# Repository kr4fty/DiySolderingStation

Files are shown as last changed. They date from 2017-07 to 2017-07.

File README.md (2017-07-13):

# Soldering Station 

Diy Estación de soldado con Atmega328 (Arduino UNO), compatible con HAKKO 936/937/928/926

## Información

Estacion de soldado hecho sobre un Atmega328, utilizando un Lapiz de una estación Hakko.

A diferencia de la estación original, esta alimenta a la Punta/Lapíz con corriente alterna (CA, 24Vac).

ATENCIÓN: Tener en cuenta que este Lapiz utiliza un PTC para el sensado de la temperatura y NO una termocupla.

<p align="center">
  <br><br>
  <b>Lapiz utilizado</b><br>
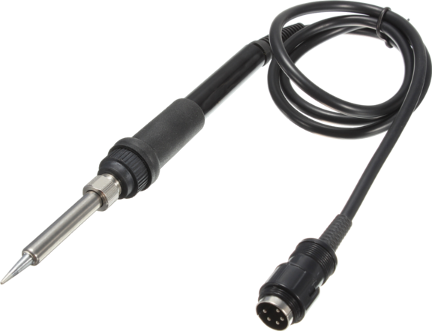
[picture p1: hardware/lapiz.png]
  
  <br>
</p>

## Caracteristicas

  * ESD, Antiestático
  * Tensión: 24 Vac 
  * Rango de temperaturas: 120-480 ºC.
  * Potencia: 50 W

## Partes

  * LCD del tipo I²C: se utilizó un lcd de un Motorola C115 (chipset ST7558)
  * Encoder rotatorio para chasis
  * Punta/lapiz de Estación de soldado, compatible con HAKKO 907 (DIN 5 ESD)
  * Botón para chasis
  * Controlador (incluido en el repositorio)

## Software

Depende de las librerias:
  * [ArduinoPID](https://github.com/br3ttb/Arduino-PID-Library): Librería para el control de la temperatura por medio de un PID
  * [ST7558](https://github.com/kr4fty/ST7558-Motorola-C115-LCD-Library): Driver para manejar el LCD
  * [TimerOne](https://github.com/PaulStoffregen/TimerOne): para el Control de Fase de la tensión de alimentación
  * [EnableInterrupt](https://github.com/GreyGnome/EnableInterrupt): Para habilitar tanto las interrupciones externas como las del tipo Pin-Change
  * [EncoderPCI](https://github.com/kr4fty/EncoderPCI): Se encarga de manejar el Encoder

## Hardware

<p align="center">
  <br><br>
  <b>Circuito eléctrico</b><br>
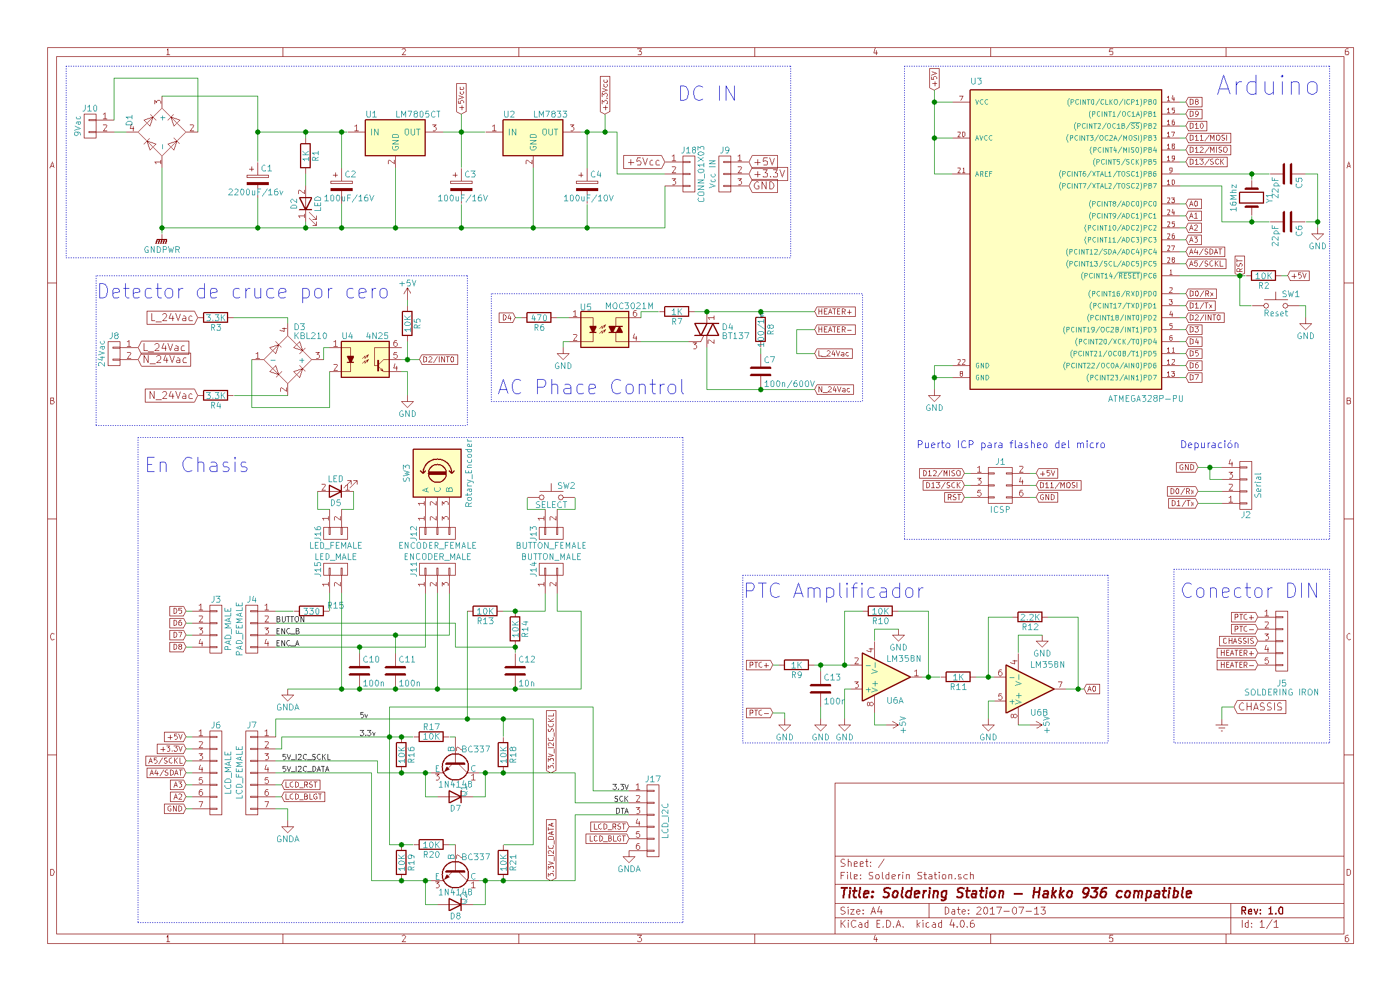
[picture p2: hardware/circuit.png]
  
  <br>
</p>

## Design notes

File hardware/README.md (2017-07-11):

## About

Created with KiCAD 4.0.6

Tapia Favio

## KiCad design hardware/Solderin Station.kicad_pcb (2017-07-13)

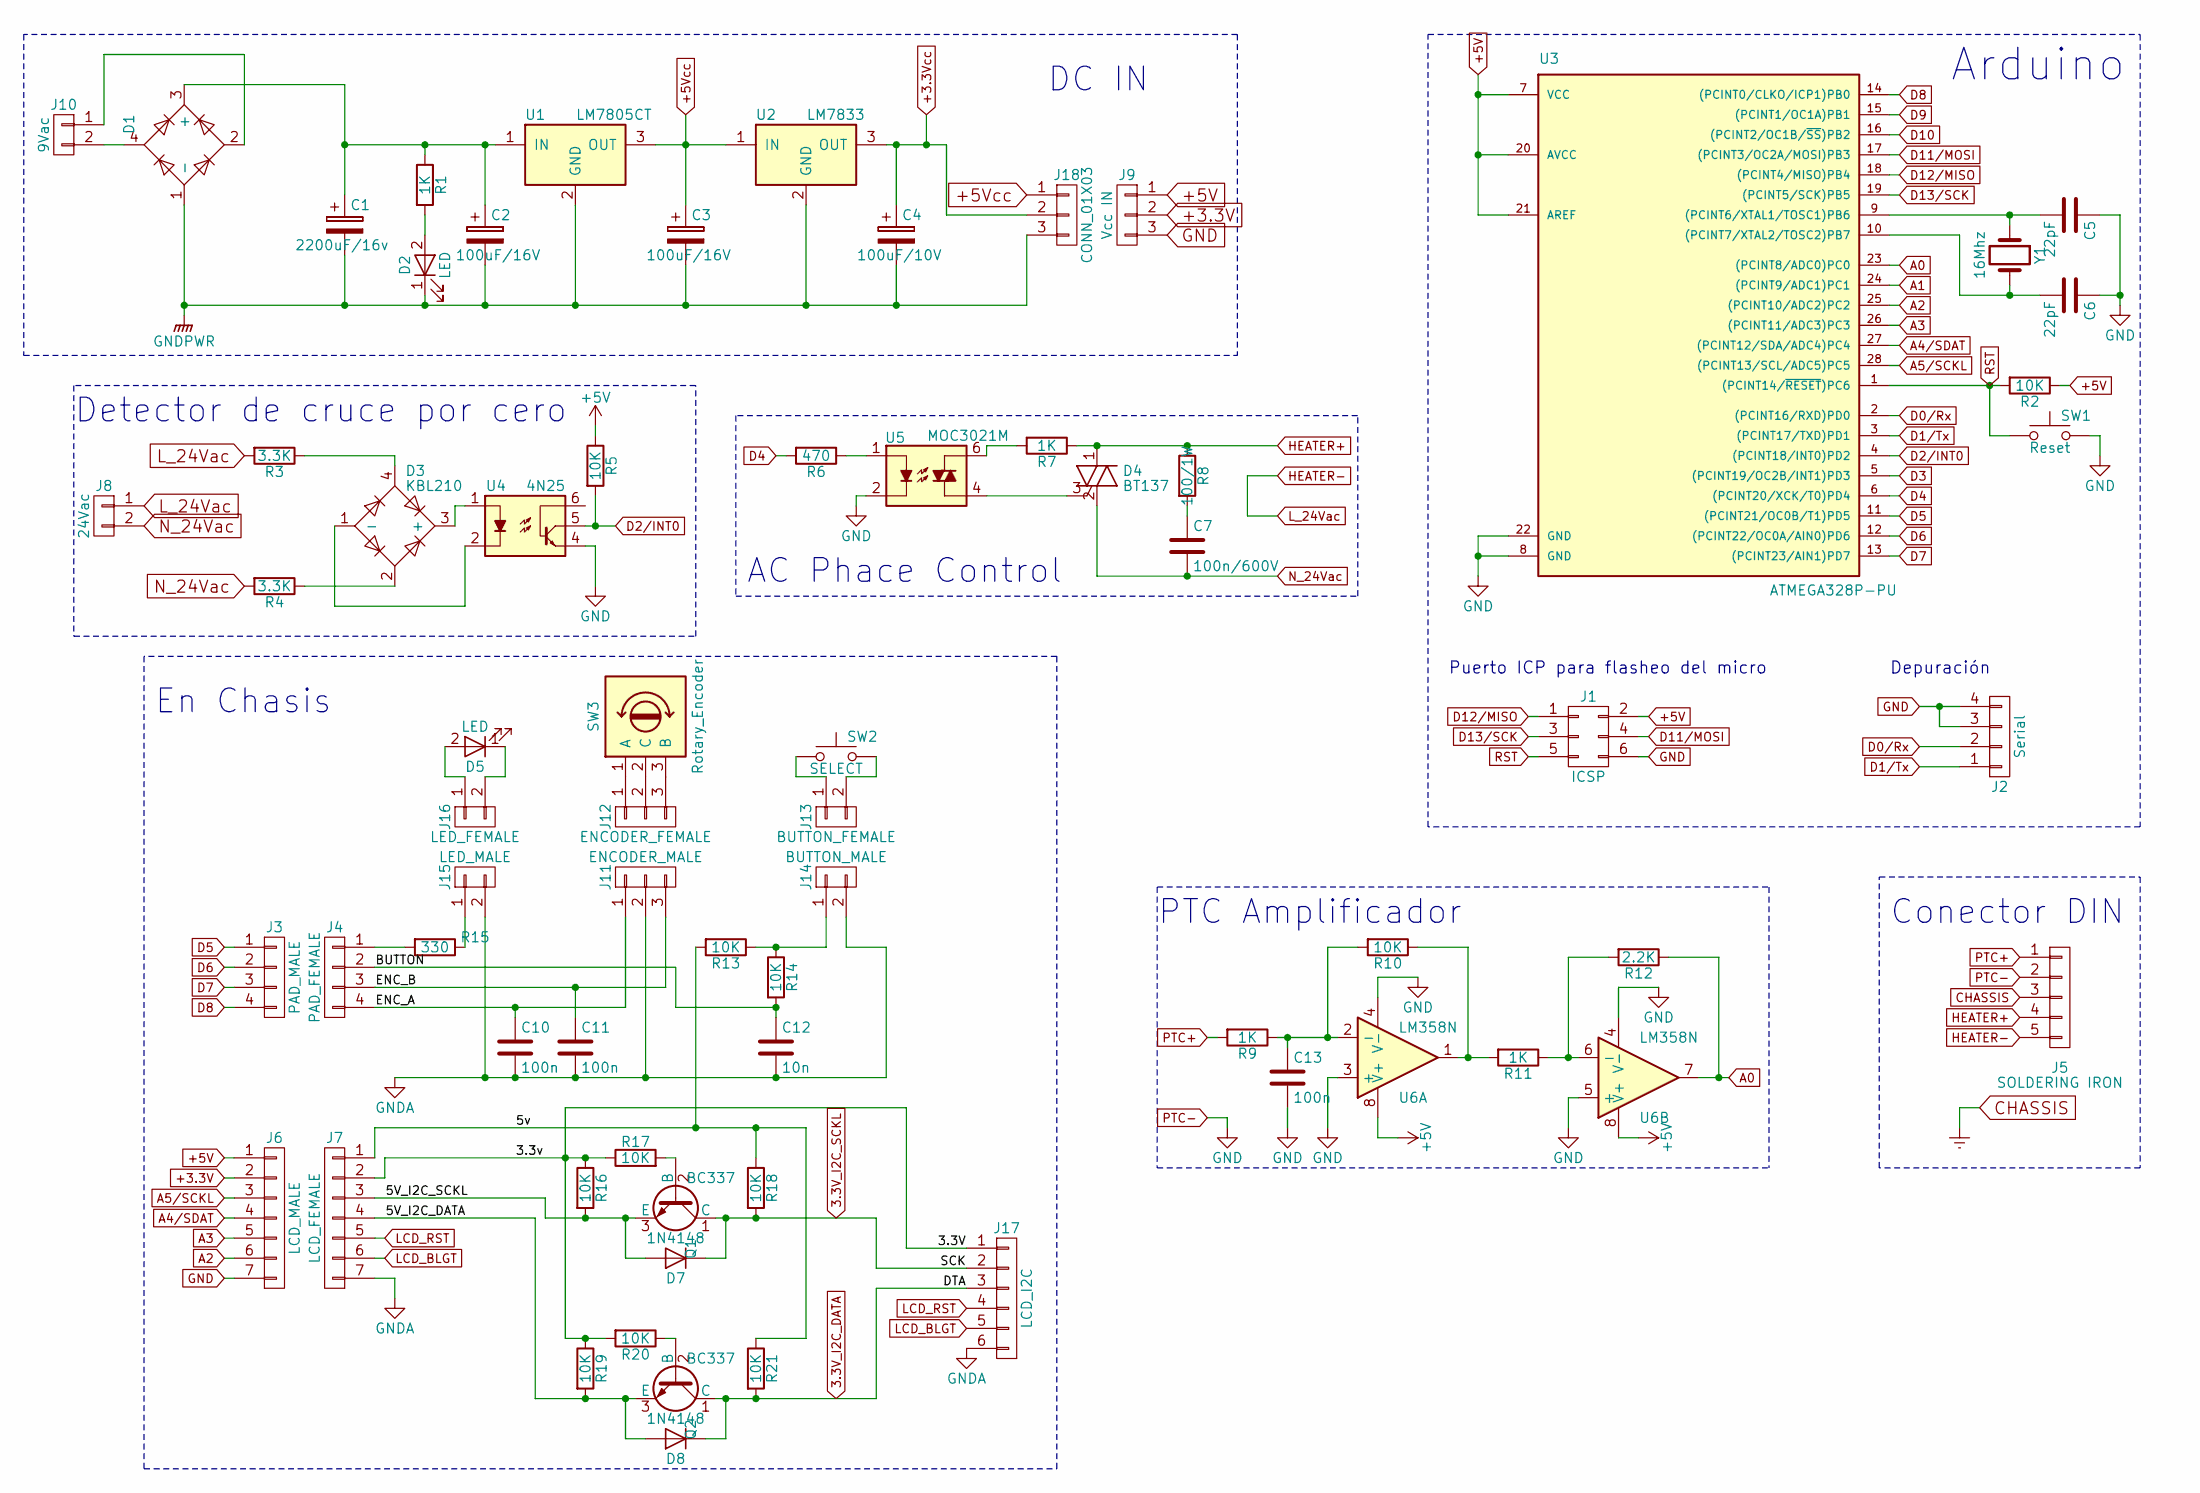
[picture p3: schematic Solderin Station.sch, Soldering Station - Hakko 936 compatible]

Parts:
C1: 2200uF/16v; CP_Radial_D12.5mm_P5.00mm
C2, C3: 100uF/16V; CP_Radial_D5.0mm_P2.50mm
C4: 100uF/10V; CP_Radial_D5.0mm_P2.50mm
C5, C6: 22pF; C_Disc_D3.8mm_W2.6mm_P2.50mm
C7: 100n/600V; C_Rect_L11.0mm_W3.5mm_P10.00mm_MKT
C10, C11, C13: 100n; C_Disc_D3.8mm_W2.6mm_P2.50mm
C12: 10n; C_Disc_D3.8mm_W2.6mm_P2.50mm
D1: D_Bridge_-A+A; Diode_Bridge_18.5x5.5
D2, D5: LED; LED_D3.0mm
D3: KBL210; Diode_Bridge_18.5x5.5
D4: BT137; TO-220_Vertical
D7, D8: 1N4148; D_DO-35_SOD27_P7.62mm_Horizontal
J1: ICSP; Pin_Header_Straight_2x03_Pitch2.54mm
J2: Serial; Pin_Header_Straight_1x04_Pitch2.54mm
J3: PAD_MALE; Pin_Header_Straight_1x04_Pitch2.54mm
J4: PAD_FEMALE; Pin_Header_Straight_1x04_Pitch2.54mm
J5: SOLDERING IRON; Pin_Header_Straight_1x05_Pitch2.54mm
J6: LCD_MALE; Pin_Header_Straight_1x07_Pitch2.54mm
J7: LCD_FEMALE; Pin_Header_Straight_1x07_Pitch2.54mm
J8: 24Vac; WireConnection_2.50mmDrill_LargePad
J9: Vcc IN; PINHEAD1-3
J10: 9Vac; WireConnection_2.50mmDrill_LargePad
J11: ENCODER_MALE; PINHEAD1-3
J12: ENCODER_FEMALE; PINHEAD1-3
J13: BUTTON_FEMALE; PINHEAD1-2
J14: BUTTON_MALE; PINHEAD1-2
J15: LED_MALE; PINHEAD1-2
J16: LED_FEMALE; PINHEAD1-2
J17: LCD_I2C; PINHEAD1-6
J18: CONN_01X03; Pin_Header_Straight_1x03_Pitch2.54mm
Q1, Q2: BC337; TO-92_Inline_Narrow_Oval
R1: 1K; R_Axial_DIN0207_L6.3mm_D2.5mm_P7.62mm_Horizontal
R2, R5, R13, R14, R18, R21: 10K; R_Axial_DIN0204_L3.6mm_D1.6mm_P5.08mm_Horizontal
R3, R4: 3.3K; R_Axial_DIN0207_L6.3mm_D2.5mm_P7.62mm_Horizontal
R6: 470; R_Axial_DIN0204_L3.6mm_D1.6mm_P5.08mm_Horizontal
R7, R9, R11: 1K; R_Axial_DIN0204_L3.6mm_D1.6mm_P5.08mm_Horizontal
R8: 100/1W; R_Axial_DIN0207_L6.3mm_D2.5mm_P7.62mm_Horizontal
R10, R16, R17, R19, R20: 10K; R_Axial_DIN0204_L3.6mm_D1.6mm_P2.54mm_Vertical
R12: 2.2K; R_Axial_DIN0204_L3.6mm_D1.6mm_P2.54mm_Vertical
R15: 330; R_Axial_DIN0204_L3.6mm_D1.6mm_P5.08mm_Horizontal
SW1: Reset; SW_PUSH_6mm
SW2: SELECT; SW_PUSH_6mm
SW3: Rotary_Encoder; Potentiometer_Bourns_PTV09A-1_Horizontal
U1: LM7805CT; TO-220_Vertical
U2: LM7833; TO-220_Vertical
U3: ATMEGA328P-PU; DIP-28_W7.62mm
U4: 4N25; DIP-6_W7.62mm
U5: MOC3021M; DIP-6_W7.62mm
U6: LM358N; DIP-8_W7.62mm_LongPads
Y1: 16Mhz; Crystal_HC52-6mm_Vertical

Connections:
3.3V_I2C_DATA: D8.1 (K), J17.3, Q2.1 (C), R21.2
3.3V_I2C_SCKL: D7.1 (K), J17.2, Q1.1 (C), R18.2
+3.3V: J6.2, J9.2
+3.3Vcc: C4.1, J18.2, U2.3 (OUT)
+5V: J1.2, J6.1, J9.1, R2.1, R5.1, U3.7 (VCC), U3.20 (AVCC), U3.21 (AREF), U6.8 (V+)
+5Vcc: C3.1, J18.1, U1.3 (OUT), U2.1 (IN)
/3.3V: J7.2, J17.1, R16.1, R17.1, R19.1, R20.2
/5V_I2C_DATA: D8.2 (A), J7.4, Q2.3 (E), R19.2
/5V_I2C_SCKL: D7.2 (A), J7.3, Q1.3 (E), R16.2
/5v: J7.1, R13.2, R18.1, R21.1
/BUTTON: C12.1, J4.2, R14.2
/ENC_A: C10.1, J4.4, J11.1
/ENC_B: C11.1, J4.3, J11.3
A0: R12.1, U3.23 ((PCINT8/ADC0)PC0), U6.7
A1: U3.24 ((PCINT9/ADC1)PC1)
A2: J6.6, U3.25 ((PCINT10/ADC2)PC2)
A3: J6.5, U3.26 ((PCINT11/ADC3)PC3)
A4/SDAT: J6.4, U3.27 ((PCINT12/SDA/ADC4)PC4)
A5/SCKL: J6.3, U3.28 ((PCINT13/SCL/ADC5)PC5)
CHASSIS: J5.3
D0/Rx: J2.2, U3.2 ((PCINT16/RXD)PD0)
D1/Tx: J2.1, U3.3 ((PCINT17/TXD)PD1)
D2/INT0: R5.2, U3.4 ((PCINT18/INT0)PD2), U4.5
D3: U3.5 ((PCINT19/OC2B/INT1)PD3)
D4: R6.2, U3.6 ((PCINT20/XCK/T0)PD4)
D5: J3.1, U3.11 ((PCINT21/OC0B/T1)PD5)
D6: J3.2, U3.12 ((PCINT22/OC0A/AIN0)PD6)
D7: J3.3, U3.13 ((PCINT23/AIN1)PD7)
D8: J3.4, U3.14 ((PCINT0/CLKO/ICP1)PB0)
D9: U3.15 ((PCINT1/OC1A)PB1)
D10: U3.16 ((PCINT2/OC1B/~SS~)PB2)
D11/MOSI: J1.4, U3.17 ((PCINT3/OC2A/MOSI)PB3)
D12/MISO: J1.1, U3.18 ((PCINT4/MISO)PB4)
D13/SCK: J1.3, U3.19 ((PCINT5/SCK)PB5)
GND: C5.1, C6.1, C13.2, J1.6, J2.3, J2.4, J5.2, J6.7, J9.3, SW1.2, U3.8 (GND), U3.22 (GND), U4.4, U5.2, U6.3 (+), U6.4 (V-), U6.5 (+)
GNDA: C10.2, C11.2, C12.2, J7.7, J11.2, J14.2, J15.2, J17.6
GNDPWR: C1.2, C2.2, C3.2, C4.2, D1.1 (-), D2.1 (K), J18.3, U1.2 (GND), U2.2 (GND)
HEATER+: D4.1 (A1), J5.4, R7.1, R8.1
HEATER-: J5.5, J8.1, R3.2
LCD_BLGT: J7.6, J17.5
LCD_RST: J7.5, J17.4
N_24Vac: C7.2, D4.2 (A2), J8.2, R4.2
unnamed: C1.1, C2.1, D1.3 (+), R1.1, U1.1 (IN)
unnamed: C5.2, U3.9 ((PCINT6/XTAL1/TOSC1)PB6), Y1.1
unnamed: C6.2, U3.10 ((PCINT7/XTAL2/TOSC2)PB7), Y1.2
unnamed: C7.1, R8.2
unnamed: C13.1, R9.1, R10.2, U6.2 (-)
unnamed: D1.2, J10.1
unnamed: D1.4, J10.2
unnamed: D2.2 (A), R1.2
unnamed: D3.1 (-), U4.2
unnamed: D3.2, R4.1
unnamed: D3.3 (+), U4.1
unnamed: D3.4, R3.1
unnamed: D4.3 (G), U5.4
unnamed: D5.1 (K), J16.2
unnamed: D5.2 (A), J16.1
unnamed: J4.1, R15.2
unnamed: J12.1, SW3.1 (A)
unnamed: J12.2, SW3.2 (C)
unnamed: J12.3, SW3.3 (B)
unnamed: J13.1, SW2.1
unnamed: J13.2, SW2.2
unnamed: J14.1, R13.1, R14.1
unnamed: J15.1, R15.1
unnamed: Q1.2 (B), R17.2
unnamed: Q2.2 (B), R20.1
unnamed: R6.1, U5.1
unnamed: R7.2, U5.6
unnamed: R10.1, R11.2, U6.1
unnamed: R11.1, R12.2, U6.6 (-)
PTC+: J5.1, R9.2
RST: J1.5, R2.2, SW1.1, U3.1 ((PCINT14/~RESET~)PC6)

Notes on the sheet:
Puerto ICP para flasheo del micro
Depuración
DC IN
En Chasis
Detector de cruce por cero
AC Phace Control
PTC Amplificador
Arduino
Conector DIN

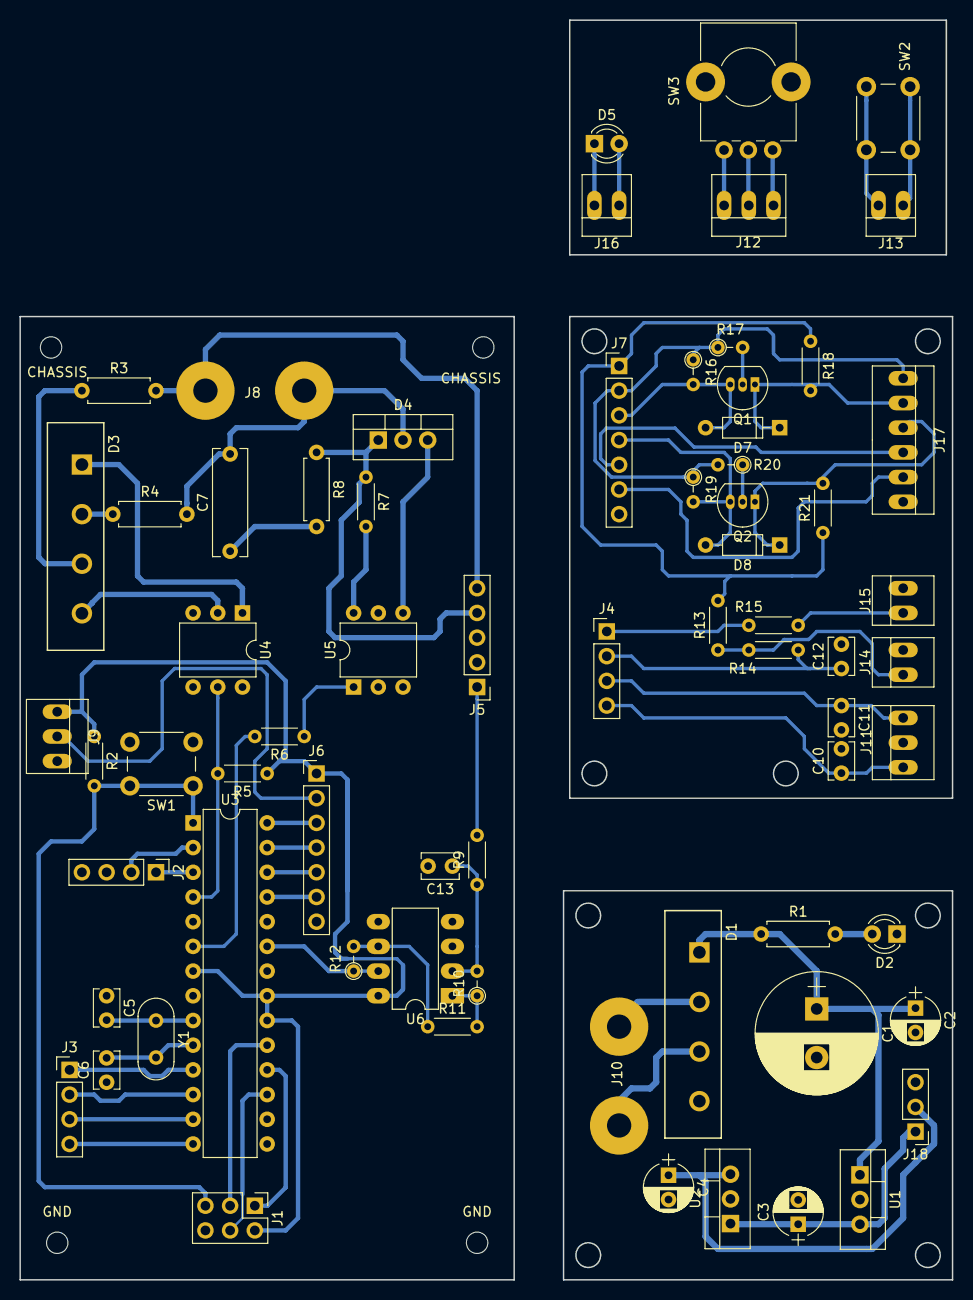
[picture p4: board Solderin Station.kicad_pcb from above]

Board: 2 copper layers, 95.9 x 129.5 mm, 73 parts (0 on the bottom side), 68 nets.

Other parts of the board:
CHASSIS: MountingHole_2.2mm_M2
CHASSIS#2: MountingHole_2.2mm_M2
GND: MountingHole_2.2mm_M2
GND#2: MountingHole_2.2mm_M2

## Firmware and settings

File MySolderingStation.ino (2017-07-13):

/*
 * Estacion de soldado hecho sobre un ATMEGA328p utilizando un Lapiz compatible
 * con la estacion HAKKO 907 (con ESD)
 *
 * Autor:
 *       Tapia Favio ( technicc(at)gmail.com )
*/

#include <Arduino.h>
#include <PID_v1.h>
#include <Wire.h>
#include <Adafruit_GFX.h>
#include <ST7558.h>
#include <TimerOne.h>
#define  LIBCALL_ENABLEINTERRUPT
#include <EnableInterrupt.h>
#include <EncoderPCI.h>
#include <EEPROM.h>
#include "config.h"

double   setPoint,
         input,
         output,
         aggKp=50,
         aggKi=0.5,
         aggKd=0.01,
         consKp=10,
         consKi=0.5,
         consKd=0.001;
volatile bool     zc;
volatile uint16_t dimtime;
volatile uint8_t  cont;

unsigned long nextCheck, nextCheckLed, timePush, timeChange;
uint16_t oldAdc, adc;
uint16_t newPos, oldPos;
uint16_t oldSetPoint;
uint8_t  uNt, dNt, cNt, uOt, dOt, cOt;
bool     enabled=false, oldEnabled, firstTime=true, BoN;
bool     ledSate;

#ifdef DEBUG
  unsigned long start, stop;
#endif

union {
  uint16_t setPoint_ee;
  uint8_t sp_uint8[2];
}_eeprom;

PID      myPID(&input, &output, &setPoint, consKp, consKi, consKd, DIRECT);
ST7558   lcd(LCDRESETPIN);
Encoder  myEnc(INA, INB);

void setup() {
  // put your setup code here, to run once:
  pinMode(TcPin,           INPUT);
  pinMode(zeroCrossPin,    INPUT);
  pinMode(acPwmPin,        OUTPUT);
  pinMode(LCDBACKLIGHTPIN, OUTPUT);
  pinMode(BUTTON,          INPUT);
  pinMode(LEDPIN,          OUTPUT);

  myPID.SetSampleTime(50);
  myPID.SetOutputLimits(0, STEPS);
  //turn the PID on
  myPID.SetMode(AUTOMATIC);

  enableInterrupt(zeroCrossPin, zeroCrossInterrupt, FALLING);
  Timer1.initialize(freqStep);
  Timer1.attachInterrupt(dim_check, freqStep);

  lcd.init();
  lcd.cp437(true);
  lcd.setContrast(75);
  digitalWrite(LCDBACKLIGHTPIN, HIGH);
  printBase();

/*
 * Recupero la ultima temperatura seteada. La misma se guarda en la EEPROM
*/
  _eeprom.sp_uint8[0]= EEPROM.read(0);
  _eeprom.sp_uint8[1]= EEPROM.read(1);
  if(_eeprom.setPoint_ee>500)
    _eeprom.setPoint_ee = 300;

  myEnc.write(_eeprom.setPoint_ee);

  #ifdef DEBUG
    Serial.begin(9600);
  #endif
}

void loop() {
  // put your main code here, to run repeatedly:
  uint16_t      gap, newTemp=0;
  bool          tuningState=false;       // 0: conservative, 1: agresive
  bool          button;

/* Inicio de seleccion de proceso
 *
 *   si es la primera que se ejecuta o cancelo la tarea previa, entonces:
 *      - mueva el encoder para seleciona la temperatura deseada
 *      - y con un pulso corto se comienza el proceso de calentar la punta
 *      - un pulso largo no tiene efecto alguno aca
 *   si el sistema ya estaba funcionando y con una temperatura setada, entonces
 *      - un pulso corto PAUSA/DETIENE el calentamiento de la punta
 *      - con solo mover el encoder, el setPoint se setea automaticamente a la
 *        posicion
 *   y si el sistema ya estaba seteado la temperatura pero pausado/detenido:
 *      - un pulso corto REANUDA el proceso
 *      - un pulso largo CANCELA el proceso
 */

  newPos = myEnc.read();
  button = digitalRead(BUTTON);
  if(!button){
    timePush=millis();
    while(!button)
      button = digitalRead(BUTTON);
    if(millis()<(timePush+200) || firstTime){
      if(firstTime){        // Solo se ejecuta cuando arranca o cuando se
        firstTime = false;  // cancela el proceso actual

        _eeprom.setPoint_ee = newPos;
        EEPROM.write(0, _eeprom.sp_uint8[0]);
        EEPROM.write(1, _eeprom.sp_uint8[1]);

        setPoint = newPos;
        enabled = true;
        nextCheck = millis()+500;
        nextCheckLed = nextCheck;

        #ifdef DEBUG
          Serial.println("Iniciando");
        #endif
      }
      else
        enabled=not enabled;
    }
    else if(millis()>=(timePush+200)) {
      if(!enabled){ // Cancelo el proceso actual
        firstTime = true;
        oldPos--;  // Para evitar que quede el texto en blanco sobre negro
                   // Como la condicion para actualizar el display es que
        dOt--;     // cambien los vlores actuales en comparacion a los guardados
        cOt--;     // entonces fuerzo a que sean distintos. De este modo voy a
        uOt--;     // mostrar el estado de la temperatura como del setPoint
        printBase();
      }
    }
  }
  else{
    if(newPos!=oldPos){
      _eeprom.setPoint_ee = newPos;
      EEPROM.write(0, _eeprom.sp_uint8[0]);
      EEPROM.write(1, _eeprom.sp_uint8[1]);

      setPoint = newPos;
    }
  }// fin seleccion de proceso

  // control PID
  adc = analogRead(TcPin);
  adc = (float)((X*oldAdc + adc)/(X+1));      // Filtro digital pasa bajos
  oldAdc = (uint16_t)adc;

  if(adc<338) // es para hacer un estimativo a temperaturas menores de 150ºc
    input = map(oldAdc, 172, 338, 0, 150);  // entre 0 y 150 ºc
  else        // a partir de 150ºc el ptc tiene mayor precision en la medicion
    input = map(oldAdc, 338, 585, 150, 350); // entre 150 y 350 ºc
  if(input<0)
    input = 0;

  newTemp = (uint16_t)input;

/*
 *  Descompongo newTemp en sus digitos, centena-decena-unidad, para lograr una
 *  mayor velocidad en la actualizacion del display. Resulta mas rapido imprimir
 *  el digito que cambio en lugar de todo el numero.
 *   ejemplo:
 *           si newTemp = 359
 *                           => cNT=3, dNt=5 y uNt=9
*/
  cNt = (uint8_t)(newTemp/100);               // centena de newTemp
  dNt = (uint8_t)((uint16_t)newTemp%100)/10;  // decena  de newTemp
  uNt = (uint8_t)((uint16_t)newTemp%10);      // unidad  de newTemp

/*
 * Una vez que se seleciono el setPoint y se dio arranque al proceso, el PID
 * se encargara de mantener la temperatura lo mas estable posible. Solo se
 * ejecuta si el proceso NO esta pausado/detenido.
*/
  if(enabled){
    gap = abs(setPoint-input);
    if(gap<5){
      if(tuningState!=0){
        myPID.SetTunings(consKp, consKi, consKd);
        tuningState = 0;
      }
    }
    else{
      if(tuningState!=1){
        myPID.SetTunings(aggKp, aggKi, aggKd);
        tuningState = 1;
      }
    }
    myPID.Compute();
  }
  else
    output = 0;
  // fin control PID

/*
 * El setPoint esta seteado sin importar so se esta ejecutando o esta detenido,
 * por lo que llegado a un determinado margen de temperaturas, el LED comenzara
 * a parpadear, mas o menos rapido, depdendiendo de que tan cerca este de la
 * temperatura fijada.
*/
  if(!firstTime){
    // si esta dentro del rango (±15), hago parpadear el led
    if(newTemp<=setPoint-15){
      digitalWrite(LEDPIN, LOW);
      timeChange = 0;
    }
    else{
      if(abs(setPoint-newTemp)<=5)
        timeChange = 150;
      else{
         if(abs(setPoint-newTemp)<15)
          timeChange = 600;
        else{
          digitalWrite(LEDPIN, HIGH);
          timeChange = 0;
        }
      }
      if(millis()>=nextCheckLed && timeChange>0){
        ledSate = not ledSate;
        digitalWrite(LEDPIN, ledSate);

        nextCheckLed = millis()+timeChange;
      }
    }
    if(millis()>nextCheck){
      nextCheck += 500;
      // Muestro el setPoint parpadeando si no modifico la pos del encoder
      BoN = not BoN;
    }
  }

  #ifdef DEBUG
   start = millis();
  #endif

  updateDisplay();

  #ifdef DEBUG
    stop = millis();
    Serial.println((stop-start));
  #endif
}
// Solo se imprime la primera vez o cuando se ha cancelado el proceso
void printBase(){
  lcd.clearDisplay();
  lcd.setTextColor(BLACK, WHITE);
  lcd.setCursor(0, 0);
  lcd.setTextSize(2);
  lcd.print(F("T: "));

  lcd.setCursor(72, 20);
  lcd.print((char)248);
  lcd.print(F("C"));

  lcd.display();
}
/*
 * Se buscaba imprimir solo el caracter que se modifico, logrando de esta manera
 * acelerar el refresco de la pantalla.
 * Si en cambio se borra e imprime en cada ciclo de loop(), el mismo tomaba unos
 * 500ms debido a que el lcd es i²c lo que de buenas a primeras ya es un
 * protocolo muy lento en comparacion a SPI, por ejemplo.
*/
void updateDisplay()  // se muestra en el display
{
  if(firstTime && !enabled)
    BoN = true;
  lcd.setCursor(2*6*2, 0);
  lcd.setTextSize(2);
  // si el proceso esta seteado y se movio el setPoint a un nuevo valor
  if(newPos!=oldPos || enabled){
    lcd.setTextColor(BoN, not BoN);
    if(newPos<100)
      lcd.print(F(" "));
    lcd.print(newPos);
    oldPos = newPos;
  }
  else if(!firstTime && oldEnabled && !enabled){
    lcd.setTextColor(BLACK, WHITE);
    if(newPos<100)
      lcd.print(F(" "));
    lcd.print(newPos);
    lcd.print(F("  "));
  }

  // el proceso esta seteado pero pausado
  lcd.setCursor(5*6*2, 0);
  if(!firstTime && !enabled){
    if(BoN){
      lcd.print((char)222);   // '|'
      lcd.print((char)222);   // '|'
    }
    else{
      lcd.setTextColor(BLACK, WHITE);
      lcd.print(F("  "));
    }
  }
  else if(!firstTime && enabled && oldEnabled){
    lcd.setTextColor(BLACK, WHITE);
    lcd.print(F(" "));
    lcd.print((char)175);
  }

  lcd.display();

  // Si cambio la temperatura entonces muestro el nuevo valor
  if( (cNt!=cOt) || (dNt!=dOt) || (uNt!=uOt) ){
    lcd.setTextSize(4);
    lcd.setTextColor(BLACK, WHITE);

    if(cOt!=cNt){
      lcd.setCursor(0*6*4, 20);
      if(cNt==0)
        lcd.print(F(" "));
      else
        lcd.print(cNt);
      cOt = cNt;
    }
    if(dOt!=dNt){
      lcd.setCursor(1*6*4, 20);
      if(cNt==0 && dNt==0)
        lcd.print(F(" "));
      else
        lcd.print(dNt);
      dOt = dNt;
    }
    if(uOt!=uNt){
      lcd.setCursor(2*6*4, 20);
      lcd.print(uNt);
      uOt = uNt;
    }
    lcd.display();
  }

  // Siempre muestro el setPoint y el estado solo si el proceso activo
  if( ((oldEnabled!=enabled)||(oldSetPoint!=setPoint)) && !firstTime){
    lcd.setTextSize(1);
    lcd.setCursor(0, 55);
    lcd.print((uint16_t)setPoint);
    lcd.setTextColor(BLACK, WHITE);
    lcd.print(F(" "));
    lcd.print(enabled?F("Encendido"):F("Detenido!"));
    lcd.display();

    oldEnabled=enabled;
    oldSetPoint=setPoint;
  }
  #ifdef DEBUG
    lcd.setTextSize(1);
    lcd.setCursor(13*6, 55);
    lcd.print(oldAdc);
    lcd.display();
  #endif
}

// ISR's
/*
 * Encargada de detectar cuando la onda senoidal CRUZA POR CERO
 * Recordar que un TRIAC una vez que se activa, la misma conduce hasta que entre
 * T1 y T2 haya 0Vac, osea, la onda senoidal cuando cruza por cero lo desactiva
 * automaticamente. Por lo que en cada cruce se debera activar pasado un tiempo
 * de espera "dimtime".
*/
void zeroCrossInterrupt()
{
  int dimming;

  digitalWrite(acPwmPin, LOW);
  if(output>=0){
    dimming = STEPS - output; // Invierto por que una vez activado el triac no
                              // se desactiva hasta el proximo cruce por cero
    if(dimming==0){
      zc = false;
      digitalWrite(acPwmPin, HIGH);
    }
    else if(0<dimming<STEPS){
      zc = true;
      dimtime = (freqStep*dimming);
    }
    else if(dimming==STEPS){
      zc = false;
    }
  }
}
/*
 * Encargada de encender el triac tras la espera de tiempo "dimtime", simulando
 * ser el control por PWM de continua, en este caso es un control de fase.
 * Solo actua si "dimtime" esta entre 0<dimtime<255. Los casos particulares son
 * cuando es 0:siempre encendido, 255: siempre apagado.
*/
void dim_check() {
  if(zc == true){
    if(cont>=dimtime) {
      digitalWrite(acPwmPin, HIGH); // turn on light
      cont=0;                       // reset time step counter
      zc = false;                   // reset zero cross detection
    }
    else
      cont++;                       // increment time step counter
  }
}

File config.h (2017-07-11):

#define   zeroCrossPin     2 // INT0
#define   TcPin           A0 // PTC
#define   acPwmPin         4 // Control AC

#define   LEDPIN           5 // LED

//        LCDSCKPIN       A5 // I2C SCLK
//        LCDDINPIN       A4 // I2C DATA
#define   LCDRESETPIN     A3 // LCD reset
#define   LCDBACKLIGHTPIN A2 // LCD backlight pin

#define   INA              8 // Encoder A pin
#define   INB              7 // Encoder B pin
#define   BUTTON           6 // button

/* AC Phace control
 * (50Hz)-> 1/50=20ms -> 1 cycle,  1/2 cycle: 10ms
 * 10ms=10000us
 *
 * 127 steps/cycle:
 *  (10000uS)/127 steps = 78 uS/Steps
 * 255 steps/cycle:
 * (10000uS)/255 steps = 39 uS/Steps
*/
#define   STEPS           255
#define   freqStep        39

/* Filtro digital
 * valor = (X*ValorAnt + valor)/(X+1);
 * X: varilble utilizada por el flitro
 *        X=2^n - 1, 'n' cuanto mas grande mas inmune al ruido
*/
#define   X               31

//#define DEBUG 1

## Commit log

2017-07-12 ptc sensor value
2017-07-13 update firmware
    [Solderin Station.kicad_pcb, Solderin Station.sch]
2017-07-13 description is added in the .ino file
    [Solderin Station.kicad_pcb, Solderin Station.sch]
